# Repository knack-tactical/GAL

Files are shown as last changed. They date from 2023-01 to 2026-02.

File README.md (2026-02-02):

# An open-source 3D printed, Gun Aiming Laser!

<details><summary>How do I download the files from GitHub?</summary>

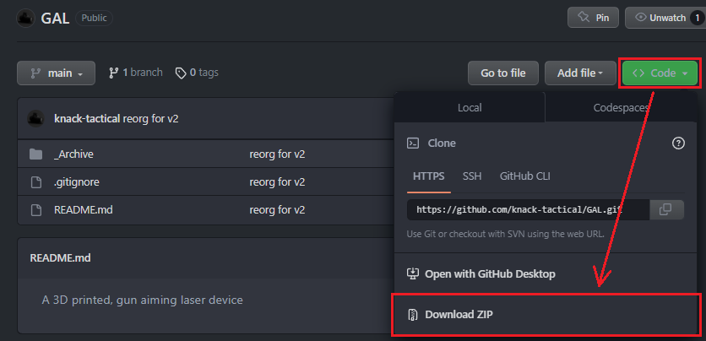
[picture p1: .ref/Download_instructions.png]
Click the green 'Code' button then 'Download ZIP'


</details>

## This project has sunset. Thank you all for your interest and support!

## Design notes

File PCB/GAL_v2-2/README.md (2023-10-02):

GAL v2.2 PCB changes from v2.1:
- Removed the area for the Pololu Buck Regulator
- Added an optional reverse polarity N-channel MOSFET (Q1)
   - This can be bypassed by shorting GND_IN to GND
   - If bypassing, conformal coating on the VCC pin is suggested

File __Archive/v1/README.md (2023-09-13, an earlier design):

# GAL
A 3D printed, gun aiming laser device

[Link to Falstad Circuit](https://tinyurl.com/2n3jw32g)

## Updated hardware from Swampdonkey's verison

Digi-key BOM: https://www.digikey.com/en/mylists/list/YLE6AURR2X

[M4x6x6mm Heatset Inserts](https://a.co/d/dzFERyy)

[850nm 3W LED](https://a.co/d/1zIGPuo)

[LED Lens](https://a.co/d/ejgL7wE)

## Things still in development
I am still working on a better retaining method for the laser zeroing, so any suggestions are appreciated!

I have designed a PCB for the GAL, which can be found [here](https://github.com/knack-69/GAL/blob/main/GAL_PCB.zip).

Also there are a few lasers I have tested with. The 980nm one is supposedly [30mW](https://www.aliexpress.us/item/2261799874302117.html). The other is a [5mW 850nm laser](https://www.aliexpress.us/item/2251832689759781.html) which is smaller and the one I will probably go with. For the 850nm laser, I bought the 'adjustable glass623' version, which performs well. Lots of testing on this front is needed. If you have any suggestions for lasers in this band, it would be appreciated as well.

## Suggested Print/Support Settings

I'd like to preface this by saying I'm not a 3D printing guru, my printers usually prints decently when I tell it to, so I don't mess around too much with the settings.
All .stl files are already in the suggested print orientation.

I would recommend not using a super large layer height (max I did was 0.18) as both male and female threads do better with smaller layer heights. Most of these pieces do not have very much interal wall volume, so using 3 walls and a lower infill (20%) should be plenty fine. Same goes with Top and Bottom layers. I usually go with 3 bottom layers and 3, which will make sure you don't see any of the infill through the top, which is especially important on the Lid, as the whole top surface is what you'll be looking at.

TL;DR: Layer Height: 0.18 | Walls: 3 | Bottom: 3 | Top: 3 | Infill 20%

### GAL Body

- Supports everywhere
- I had no issues with adhesion/warping

### GAL Lid

- Supports only on buildplate
  - This is because of the vertical laser adjustment nut hole is very small and getting supports out of it sounds terrible
- I had some issues with warping, but that might have just been me.
  - My issues with warping were because the long edge of the lid was directly at the edge of a piece of blue painters tape, which I use for bed adhesion.

### GAL Rail Mount. Battery Cover, Lens Lid

- No supports needed

### Selector Cap

- Supports everywhere

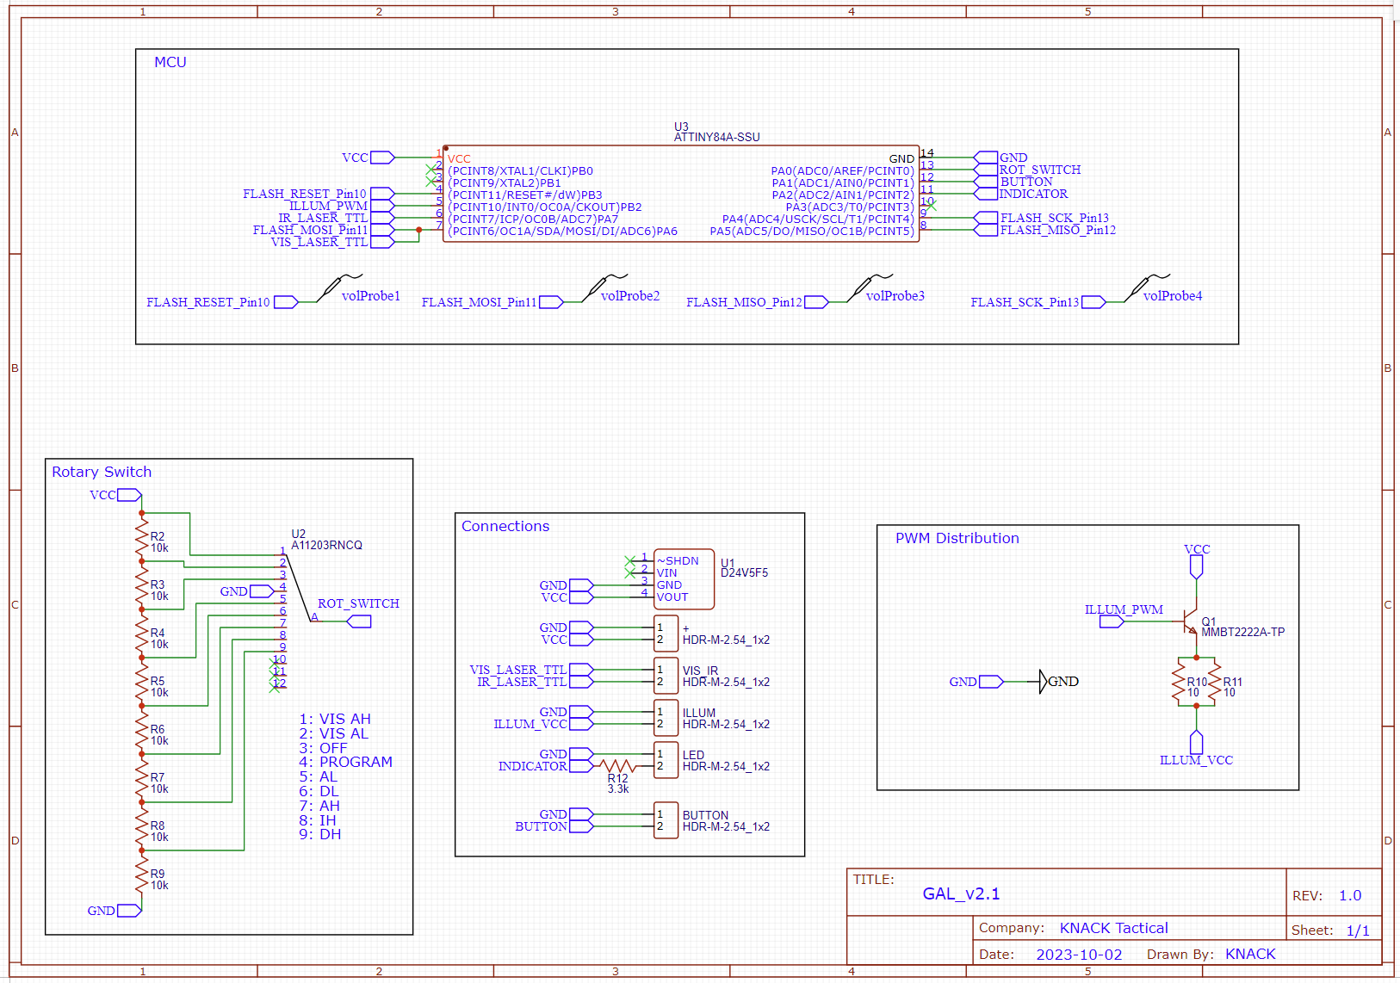
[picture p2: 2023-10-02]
PCB/GAL_v2-1/GAL_v2-1_schematic.png

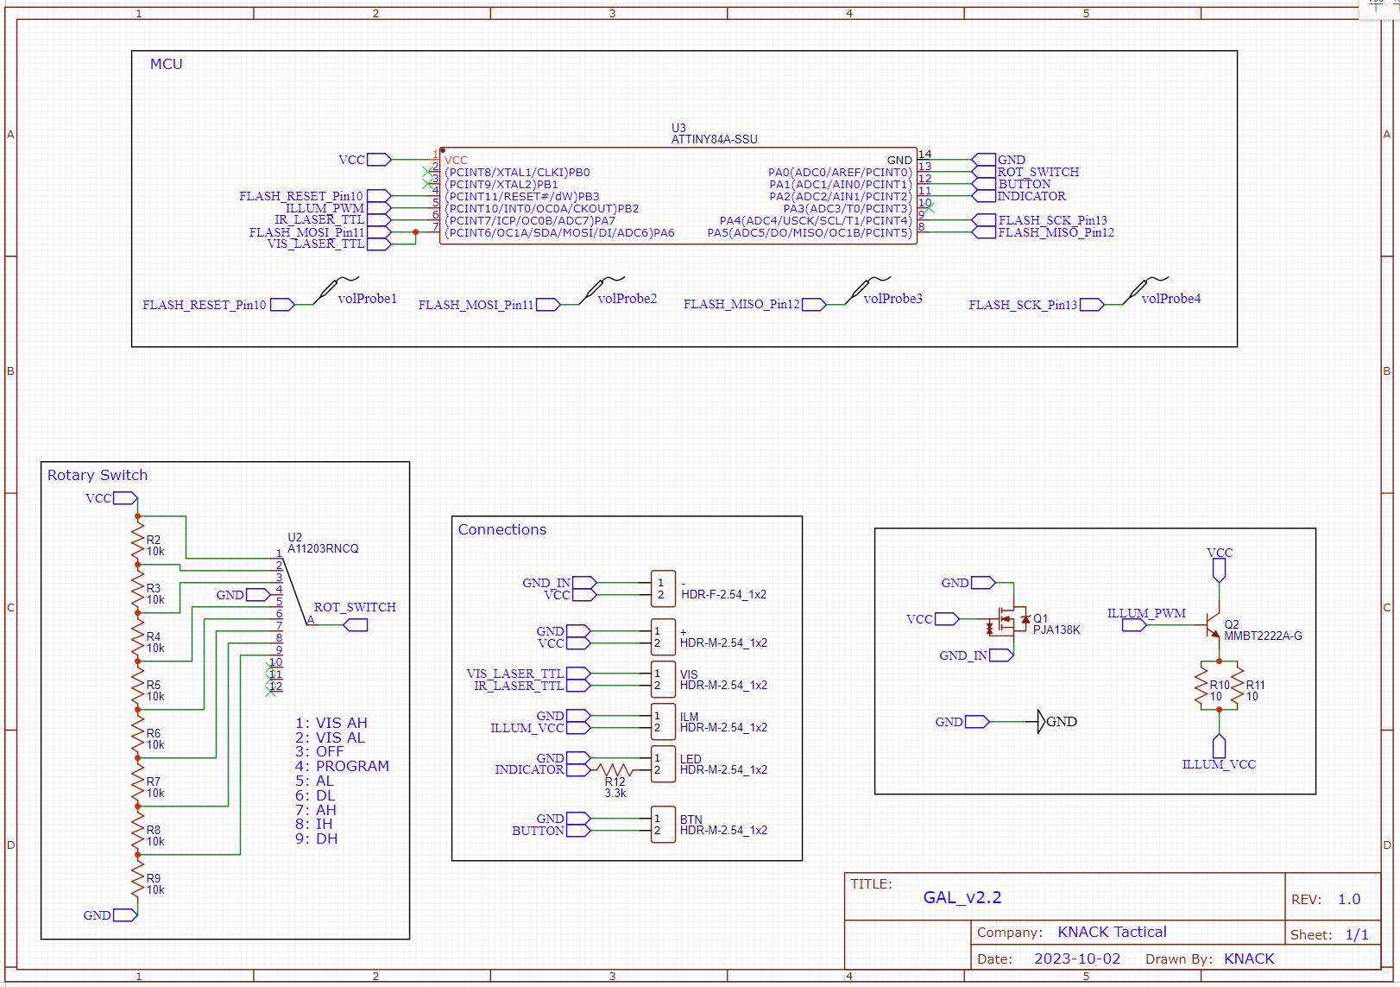
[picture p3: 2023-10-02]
PCB/GAL_v2-2/GAL_v2-2_schematic.png

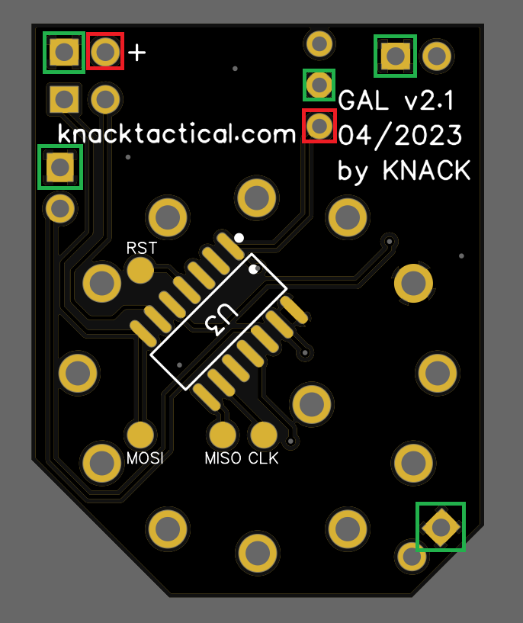
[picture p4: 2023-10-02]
attiny_program/VCC_GND_Pinout.png

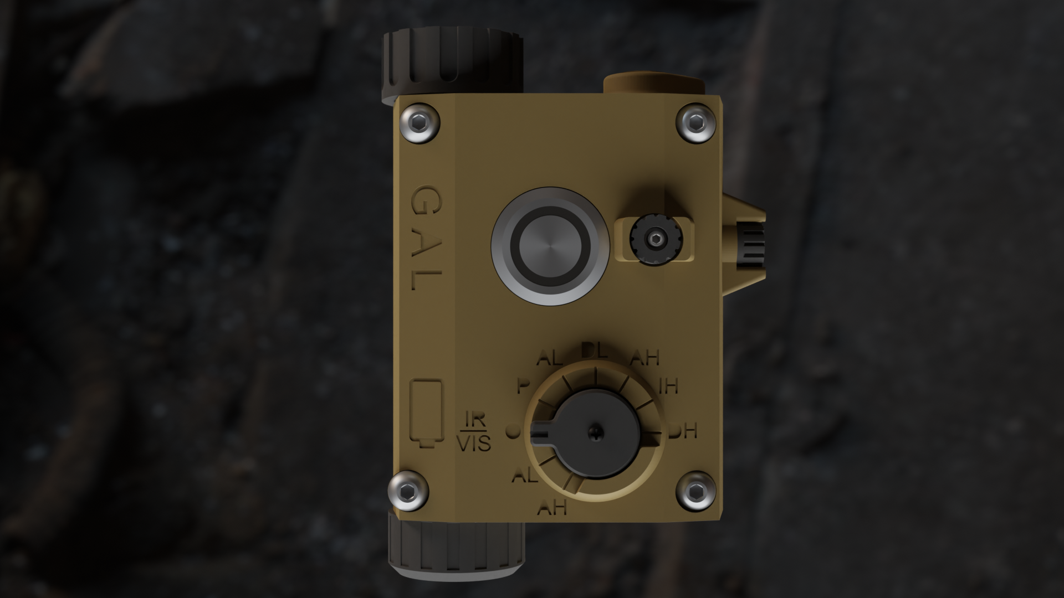
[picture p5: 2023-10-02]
Renders/top_angle_warehouse.png

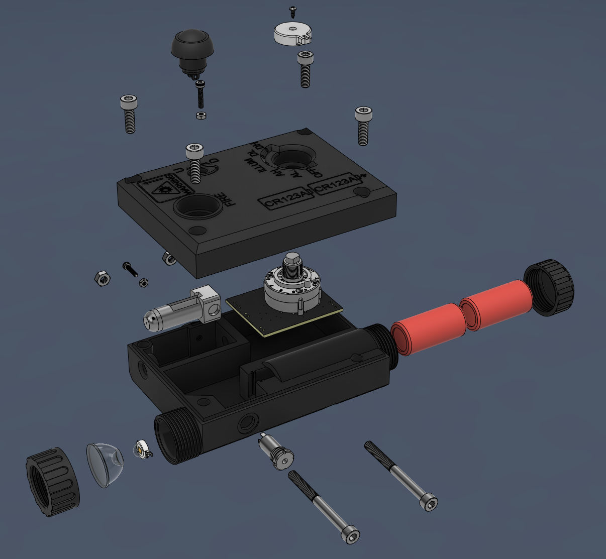
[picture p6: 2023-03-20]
RENDER/GAL_exploded_view.png

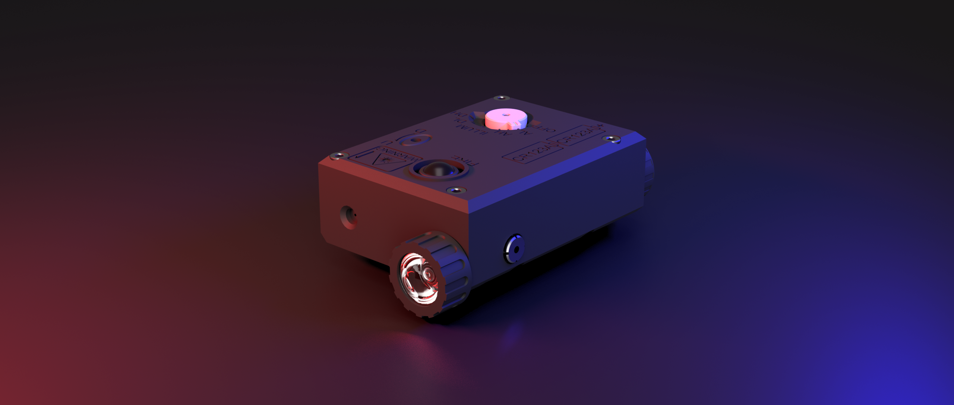
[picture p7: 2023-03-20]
RENDER/GAL_side.png

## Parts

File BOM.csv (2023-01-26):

Index | Manufacturer Part Number | Manufacturer Name | Description | Requested Quantity 1 | Pack Quantity 1 | Pack Type 1 | Digi-Key Part Number 1 | Unit Price 1 | Extended Price 1 | Minimum Order Quantity 1 | Customer Reference | Requested Part Number | Lead Weeks | Datasheet | Reference Designator | US Import Tariff | Original Part numbers | Image
1 | A20605RNCQ | C&K | SWITCH ROTARY 6POS 2.5A 125V | 1 | 1 | Tray | CKN9488-ND | 10.8 | $10.80 | 1 |  | CKN9488-ND | 16 | https://www.ckswitches.com/media/1349/arotary.pdf |  | - | CKN9488-ND | https://media.digikey.com/photos/CK%20Comp%20Photos/A20605RNCQ.jpg
2 | ASJ-203C-M-WP-HDW | Adam Tech | AUDIO JACK, WATERPROOF | 1 | 1 | Bulk | 2057-ASJ-203C-M-WP-HDW-ND | 3.91 | $3.91 | 1 |  | 2057-ASJ-203C-M-WP-HDW-ND | 10 | https://app.adam-tech.com/products/download/data_sheet/244313/asj-203c-m-wp-hdw-data-sheet.pdf |  | - | CP-2508-ND | https://media.digikey.com/Photos/Adam-Tech/ASJ-203C-M-WP-HDW.jpg
3 | PJA138K_R1_00001 | Panjit International Inc. | SOT-23, MOSFET | 1 | 1 | Cut Tape (CT) | 3757-PJA138K_R1_00001CT-ND | 0.24 | $0.24 | 1 |  | 3757-PJA138K_R1_00001CT-ND | 4 | https://www.panjit.com.tw/upload/datasheet/PJA138K.pdf |  | - | 3757-PJA138K_R1_00001CT-ND | https://media.digikey.com/Renders/~~Pkg.Case%20or%20Series/SOT-23-3%20PKG.jpg
4 | CL10B105KP8NNNC | Samsung Electro-Mechanics | CAP CER 1UF 10V X7R 0603 | 1 | 1 | Cut Tape (CT) | 1276-1946-1-ND | 0.1 | $0.10 | 1 |  | 1276-1946-1-ND | 22 | https://media.digikey.com/pdf/Data%20Sheets/Samsung%20PDFs/CL10B105KP8NNNC_Spec.pdf |  | - | 1276-1946-1-ND | https://media.digikey.com/Renders/Samsung%20Electro-Mechanics%20America/Ceramic-Capacitor-CL-Series.jpg
5 | 06035C102KAT2A | KYOCERA AVX | CAP CER 1000PF 50V X7R 0603 | 1 | 1 | Cut Tape (CT) | 478-1215-1-ND | 0.1 | $0.10 | 1 |  | 478-1215-1-ND | 12 | https://datasheets.kyocera-avx.com/X7RDielectric.pdf |  | May apply on shipments to the U.S. | 478-1215-1-ND | https://media.digikey.com/Renders/AVX%20Renders/0603-(1608-Metric)-0,90mm.jpg
6 | RNCP0805FTD1K00 | Stackpole Electronics Inc | RES 1K OHM 1% 1/4W 0805 | 3 | 3 | Cut Tape (CT) | RNCP0805FTD1K00CT-ND | 0.1 | $0.30 | 1 |  | RNCP0805FTD1K00CT-ND | 14 | https://www.seielect.com/Catalog/SEI-RNCP.pdf |  | - | RNCP0805FTD1K00CT-ND | https://media.digikey.com/Renders/Stackpole%20Renders/RNCP-Thin-Film-Chip-Resistor.jpg
7 | RC0805FR-07330RL | YAGEO | RES 330 OHM 1% 1/8W 0805 | 1 | 1 | Cut Tape (CT) | 311-330CRCT-ND | 0.1 | $0.10 | 1 |  | 311-330CRCT-ND | 20 | https://www.yageo.com/upload/media/product/productsearch/datasheet/rchip/PYu-RC_Group_51_RoHS_L_12.pdf |  | May apply on shipments to the U.S. | 311-330CRCT-ND | https://media.digikey.com/Renders/Yageo%20Renders/0805-(2012-Metric).jpg
8 | RC0805FR-073K3L | YAGEO | RES 3.3K OHM 1% 1/8W 0805 | 1 | 1 | Cut Tape (CT) | 311-3.30KCRCT-ND | 0.1 | $0.10 | 1 |  | 311-3.30KCRCT-ND | 20 | https://www.yageo.com/upload/media/product/productsearch/datasheet/rchip/PYu-RC_Group_51_RoHS_L_12.pdf |  | - | 311-3.30KCRCT-ND | https://media.digikey.com/Renders/Yageo%20Renders/0805-(2012-Metric).jpg
9 | 1N4448W-TP | Micro Commercial Co | DIODE GEN PURP 75V 250MA SOD123 | 6 | 6 | Cut Tape (CT) | 1N4448WTPMSCT-ND | 0.11 | $0.66 | 1 |  | 1N4448WTPMSCT-ND | 10 | https://www.mccsemi.com/pdf/Products/1N4448W(SOD-123).pdf |  | May apply on shipments to the U.S. | 1N4448WTPMSCT-ND | https://media.digikey.com/Renders/Micro%20Commercial%20Renders/SOD-123.jpg
10 | TLC555CDR | Texas Instruments | IC OSC SGL TIMER 2.1MHZ 8-SOIC | 1 | 1 | Cut Tape (CT) | 296-1336-1-ND | 0.85 | $0.85 | 1 |  | 296-1336-1-ND | 6 | https://www.ti.com/general/docs/suppproductinfo.tsp?distId=10 |  | - | 296-1336-1-ND | https://media.digikey.com/Renders/Texas%20Instr%20Renders/8-SOIC.jpg

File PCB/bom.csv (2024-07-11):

Designator | Footprint | Quantity | Value | LCSC Part #
C1, C2 | 0402 | 2 | 1u
J1, J2 | JST_SH_SM06B-SRSS-TB_1x06-1MP_P1.00mm_Horizontal | 2 | SM06B-SRSS-TB
J3 | PinHeader_2x03_P2.00mm_Vertical | 1 | Conn_02x03
Q1 | SOT-723 | 1 | WPM2031-3/TR
R1 | 0402 | 1 | 4.7k
R2 | 0402 | 1 | 2.55
R4 | 0402 | 1 | 1M
R5 | 0402 | 1 | 220k
SW1 | SW_Push_1P1T-SH_NO_CK_KMR2xxG | 1 | KMR221GLFS
U1 | SOIC-14_3.9x8.7mm_P1.27mm | 1 | ATtiny84A-SS
U2 | 220AMB10R-SMD | 1 | 220AMB10R
U3 | DRV0006A_NV | 1 | TPS74501PDRVR
U4 | SC-74-6_1.5x2.9mm_P0.95mm | 1 | BCR421UW6

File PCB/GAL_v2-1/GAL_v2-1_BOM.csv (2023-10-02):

ID | Name | Designator | Footprint | Quantity | Manufacturer Part | Manufacturer | Supplier | Supplier Part | Price
1 | HDR-M-2.54_1x2 | +,BUTTON,ILLUM,LED,VIS_IR | HDR-M-2.54_1X2 | 5 |  |  | LCSC | C124375 | 0.022
2 | MMBT2222A-TP | Q1 | SOT-23-3_L2.9-W1.3-P1.90-LS2.4-BR | 1
3 | 10k | R2,R3,R4,R5,R6,R7,R8,R9 | R0805 | 8 | RC0805JR-0710KL | YAGEO(国巨) | LCSC | C100047 | 0.002
4 | 10 | R10,R11 | R0805 | 2 | TC0525F100JT5E | UNI-ROYAL(厚声) | LCSC | C109436 | 0.009
5 | 3.3k | R12 | R0805 | 1 | RC0805FR-073K3L | YAGEO(国巨) | LCSC | C114531 | 0.002
6 | D24V5F5 | U1 | POLOLU_D24V5F5 | 1 | D24V5F5 | Pololu | Pololu | D24V5F5
7 | A11203RNCQ | U2 | SW-TH_CK_A112XXXXCXX | 1 | A11203RNCQ | C&K | LCSC | C411884 | 7.25
8 | ATTINY84A-SSU | U3 | SOIC-14_L8.7-W3.9-P1.27-LS6.0-BL | 1 | ATTINY84A-SSU | MICROCHIP(美国微芯) | LCSC | C144333 | 4.259

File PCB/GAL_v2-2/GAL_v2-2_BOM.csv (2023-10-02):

ID | Name | Designator | Footprint | Quantity | Manufacturer Part | Manufacturer | Supplier | Supplier Part | Price
1 | HDR-F-2.54_1x2 | GND | HDR-F-2.54_1X2 | 1 |  |  | LCSC | C49661 | 0.035
2 | ATTINY84A-SSU | U3 | SOIC-14_L8.7-W3.9-P1.27-LS6.0-BL | 1 | ATTINY84A-SSU | MICROCHIP(美国微芯) | LCSC | C144333 | 4.259
3 | 10 | R10,R11 | R0805 | 2 | TC0525F100JT5E | UNI-ROYAL(厚声) | LCSC | C109436 | 0.009
4 | MMBT2222A-G | Q2 | SOT-23-3_L2.9-W1.6-P1.90-LS2.8-BR | 1
5 | HDR-M-2.54_1x2 | VIS,BTN,LED,+,ILM | HDR-M-2.54_1X2 | 5 |  |  | LCSC | C124375 | 0.022
6 | 3.3k | R12 | R0805 | 1 | RC0805FR-073K3L | YAGEO(国巨) | LCSC | C114531 | 0.002
7 | PJA138K | Q1 | SOT-23_L2.9-W1.3-P1.90-LS2.4-BR | 1 | PJA138K_R1_00001 | PANJIT(强茂) | LCSC | C2902548 | 0.036
8 | 10k | R2,R3,R4,R5,R6,R7,R8,R9 | R0805 | 8 | RC0805JR-0710KL | YAGEO(国巨) | LCSC | C100047 | 0.002
9 | A11203RNCQ | U2 | SW-TH_CK_A112XXXXCXX | 1 | A11203RNCQ | C&K | LCSC | C411884 | 7.25

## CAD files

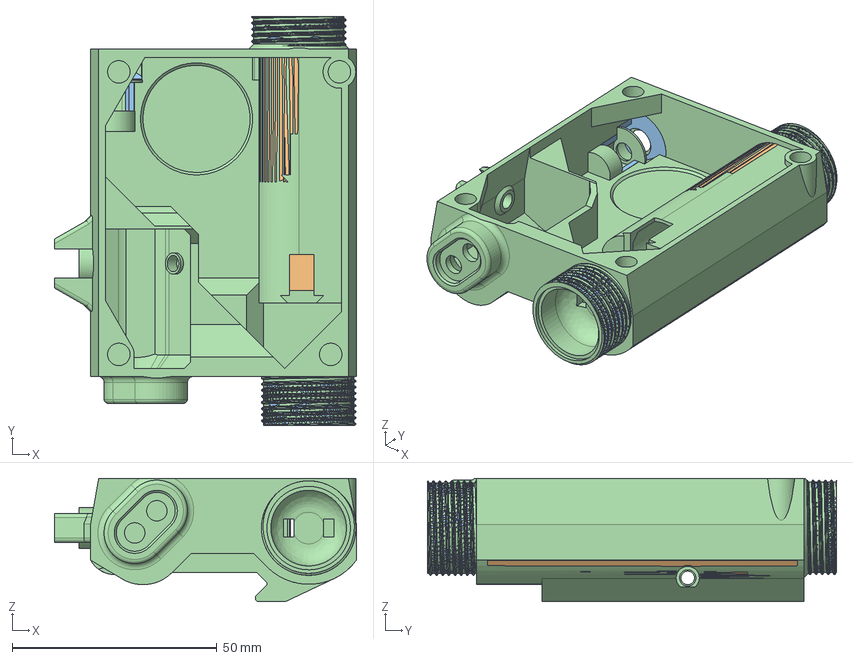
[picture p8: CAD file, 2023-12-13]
STEP/Body_Variants.step
73.8 x 100.0 x 30.2 mm
body_cr123_jack
body_cr123_crane
body_18650_jack
body_18650_crane

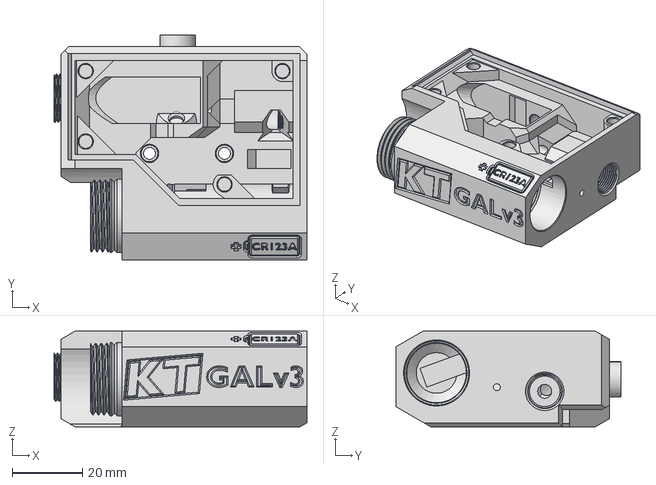
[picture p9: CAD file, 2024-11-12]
STEP/community_mods/SureFire_Pattern_Illumintor_GAL_Body.step
72.2 x 64.4 x 27.3 mm

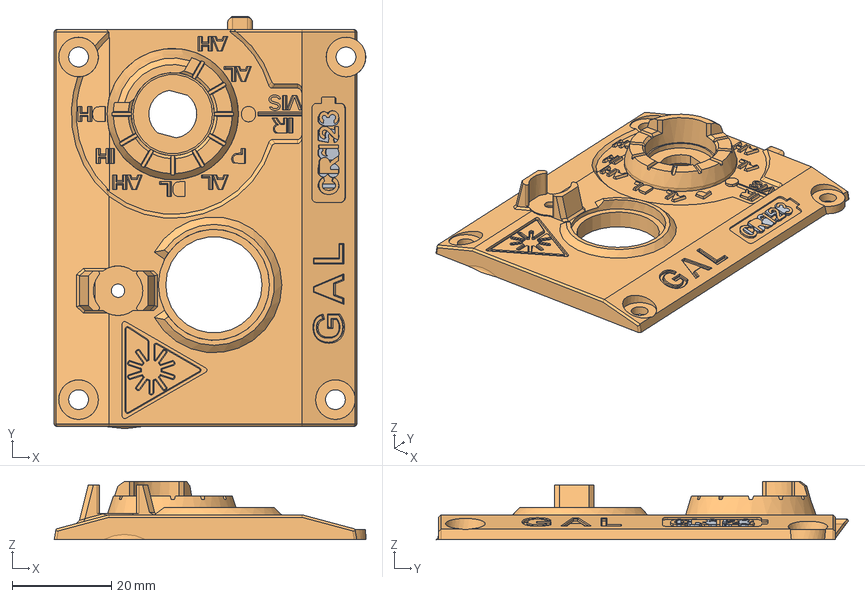
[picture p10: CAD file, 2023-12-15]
STEP/edits_by_zb/GAL_lid_variants_zb.step
62.8 x 83.1 x 11.8 mm
lid_18650_zb
lid_cr123_zb

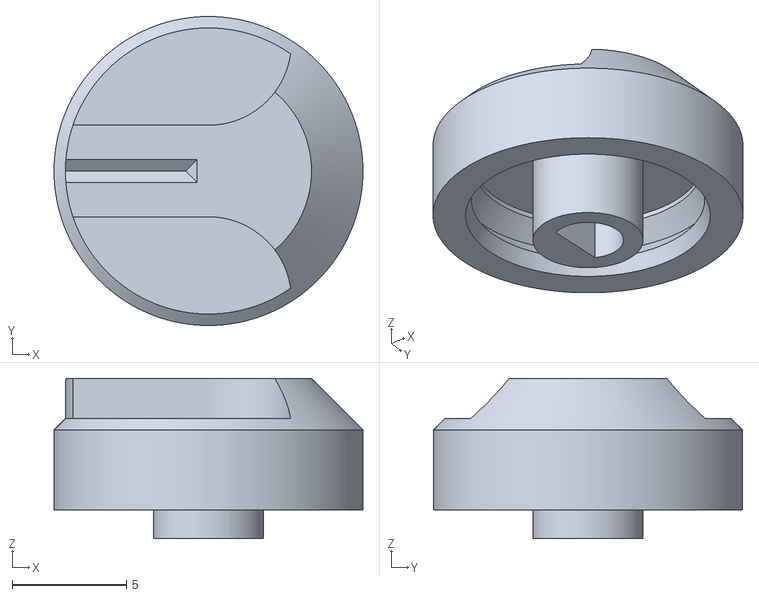
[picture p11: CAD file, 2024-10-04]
STL/11_selector_knob_2.stl
13.5 x 13.5 x 7.00

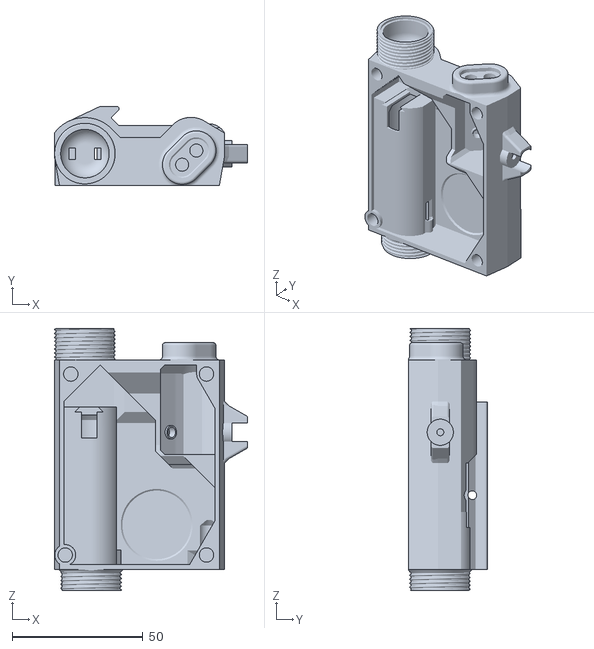
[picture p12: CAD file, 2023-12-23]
STL/body_variants/body_18650_jack.stl
73.8 x 30.2 x 100.0

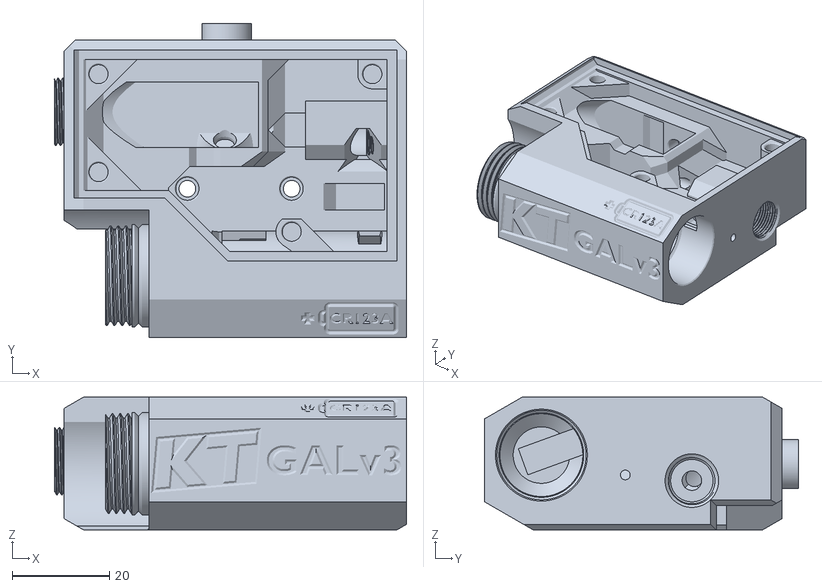
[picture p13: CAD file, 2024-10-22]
STL/community_mods/mod_02_SureFire_Pattern_Illumintor_GAL_Body.stl
72.2 x 64.4 x 27.3

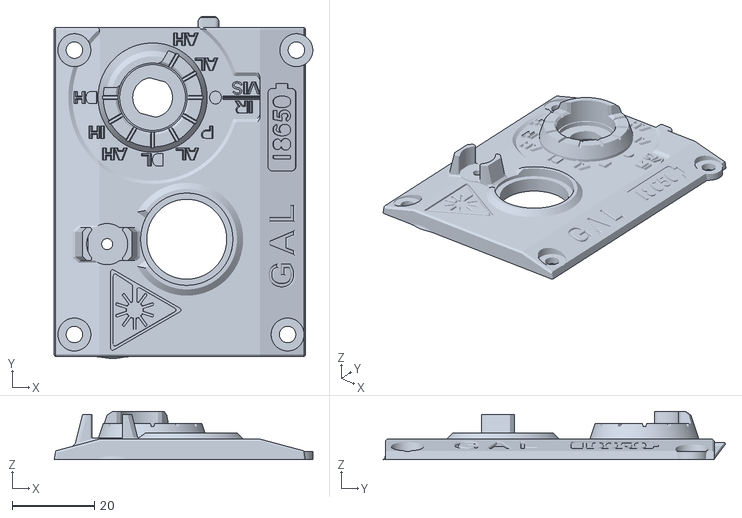
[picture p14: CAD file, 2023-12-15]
STL/edits_by_zb/GAL_lid_18650_zb.stl
62.8 x 83.1 x 11.8

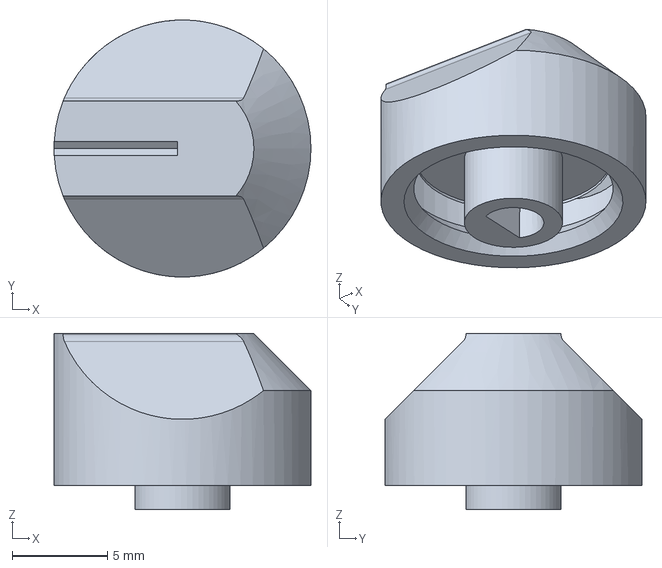
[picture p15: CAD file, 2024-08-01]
STEP/community_mods/selector_knob_zb.step
13.5 x 13.5 x 9.25 mm

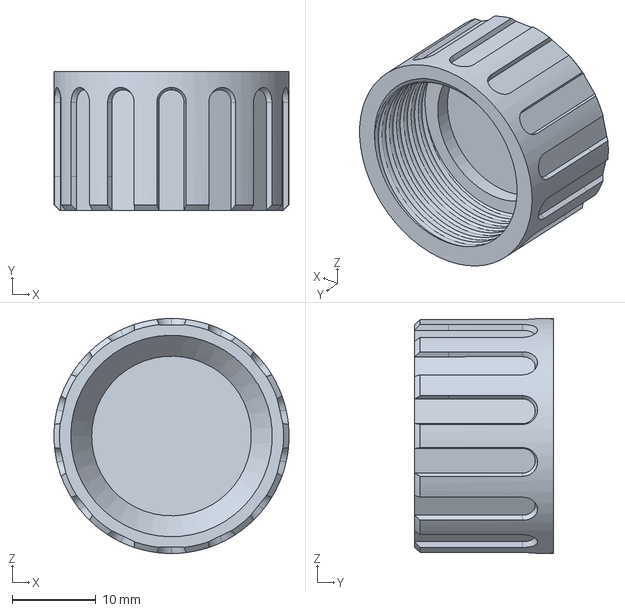
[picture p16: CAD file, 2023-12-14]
STEP/edits_by_zb/GAL_lens_cap-bezel_zb.step
28.0 x 16.5 x 28.0 mm

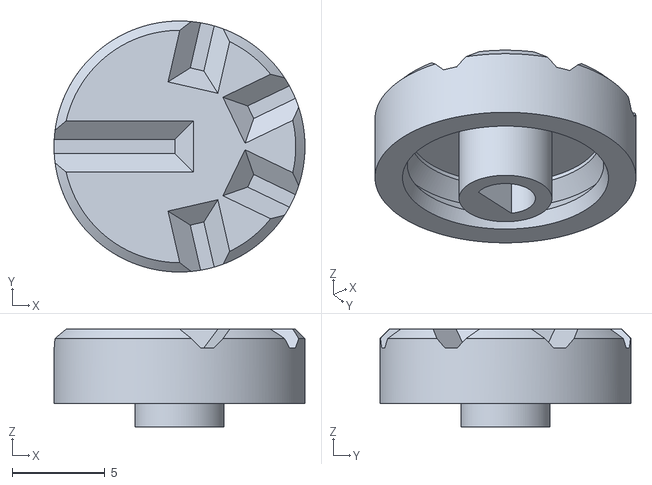
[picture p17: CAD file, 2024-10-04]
STL/11_selector_knob.stl
13.5 x 13.5 x 5.25

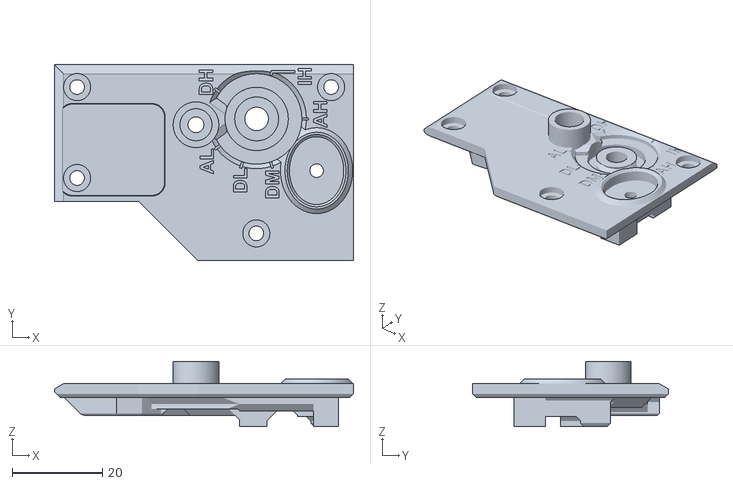
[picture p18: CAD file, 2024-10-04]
STL/community_mods/mod_03_GAL_Lid.stl
66.1 x 43.3 x 14.4

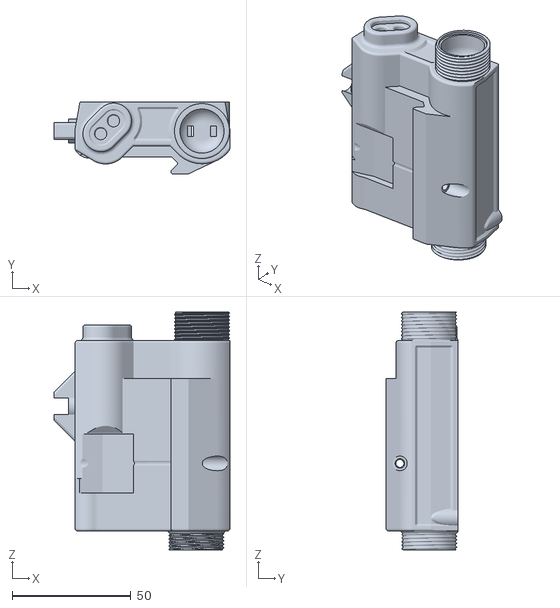
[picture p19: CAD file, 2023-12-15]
STL/edits_by_zb/GAL_body_CR123_crane_zb.stl
73.8 x 30.2 x 100.0

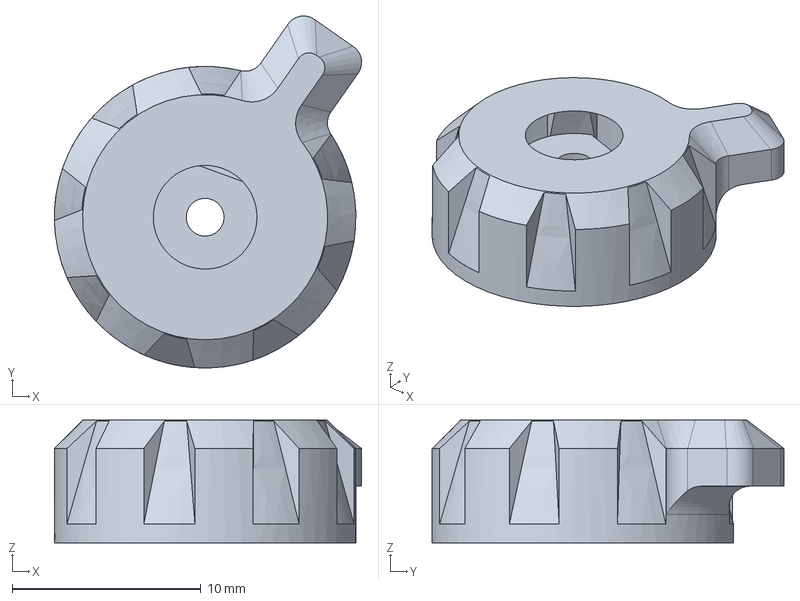
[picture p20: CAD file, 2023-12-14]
STEP/edits_by_zb/GAL_selector_knob_zb.step
16.3 x 18.7 x 6.50 mm

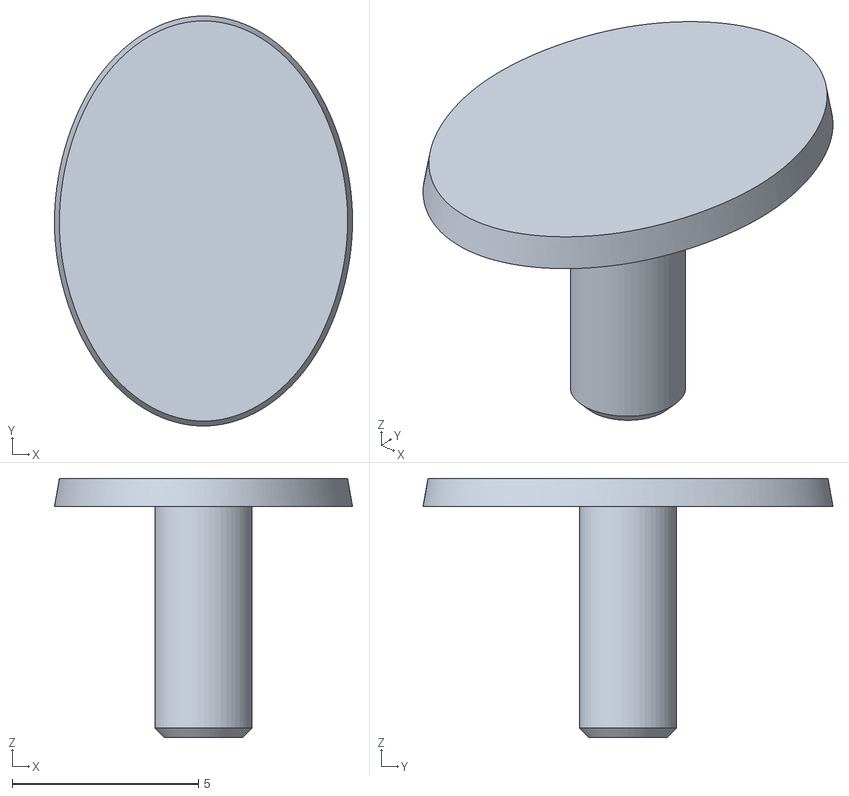
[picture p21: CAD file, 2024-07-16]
STL/12_button_post.stl
8.00 x 11.0 x 6.95

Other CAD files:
STL/community_mods/mod_03_selector_knob.stl
STL/edits_by_zb/GAL_lid_CR123_zb.stl
STEP/edits_by_zb/GAL_battery_cap_retention_zb.step
STL/07_crane_port_spacer.stl
STEP/edits_by_zb/GAL_TPU_gaskets_retention_zb.step
STL/01_GAL_body.stl
STL/02_laser_base.stl
STL/03_laser_housing.stl
STL/04_laser_lens_cap.stl
STL/05_lens_cap.stl
STL/06_lens_locking_ring.stl
STL/08_crane_port_installation_tool.stl
STL/09_battery_cap_retention_strap_TPU.stl
STL/10_GAL_lid.stl
STL/13_button_retainer.stl
STL/14_FIRE_button_TPU.stl
STL/Battery Cover.stl
STL/GAL Rail Mount.stl
STL/Laser Base.stl
STL/Laser Body.stl
STL/Selector Cap.stl
STL/adjustment_locking_knob.stl
STL/battery_cap.stl
STL/community_mods/mod_01_selector_knob_zb.stl
STL/community_mods/mod_03_GAL_Lid_reordered.stl
STL/edits_by_zb/GAL_TPU_gaskets_retention_zb.stl
STL/edits_by_zb/GAL_battery_cap_retention_zb.stl
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

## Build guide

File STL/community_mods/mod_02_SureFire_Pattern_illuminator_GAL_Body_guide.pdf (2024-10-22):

This is the GALv3 Body mod that accepts SureFire patterned flashlight heads.

This includes M300 heads, Kiji heads, Malkoff E2XT, etc.

The same o-ring used for the GALv3 adjustable illuminator can be used (15x1.5mm o-ring)

Build Instructions:

- The Illum- wire should be stripped and tinned about 0.5" long.
- Feed the wire into the hole on the inside of the threaded area until the insulation is all the way to the hole.
- This is to prevent shorting between the positive and negative terminals
- Feed the tinned wire up along the channel, and hook it over the top and back into the inside.
- Trim off any excess that goes too far into the inside area.
- The Illum+ wire should be soldered to a AAA positive terminal (no spring) and glued into the bottom of the inside area
- Some other contact can be used, just make sure it doesn’t contact the negative wire

Note: In the images, the wire colors are backwards. Take note of which wire you are wires you are wiring to which part.

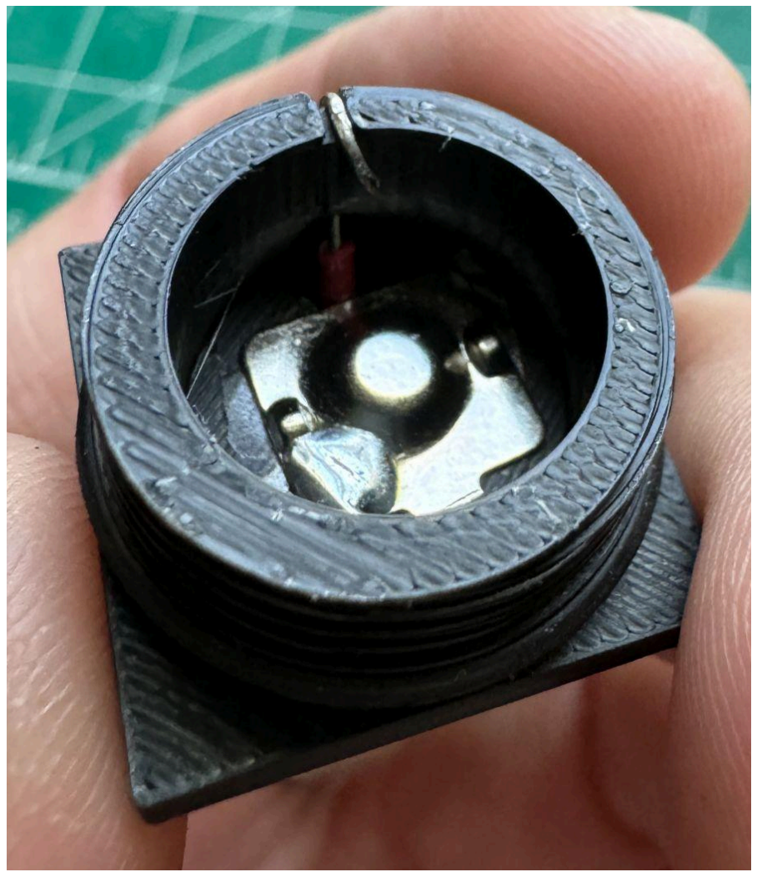
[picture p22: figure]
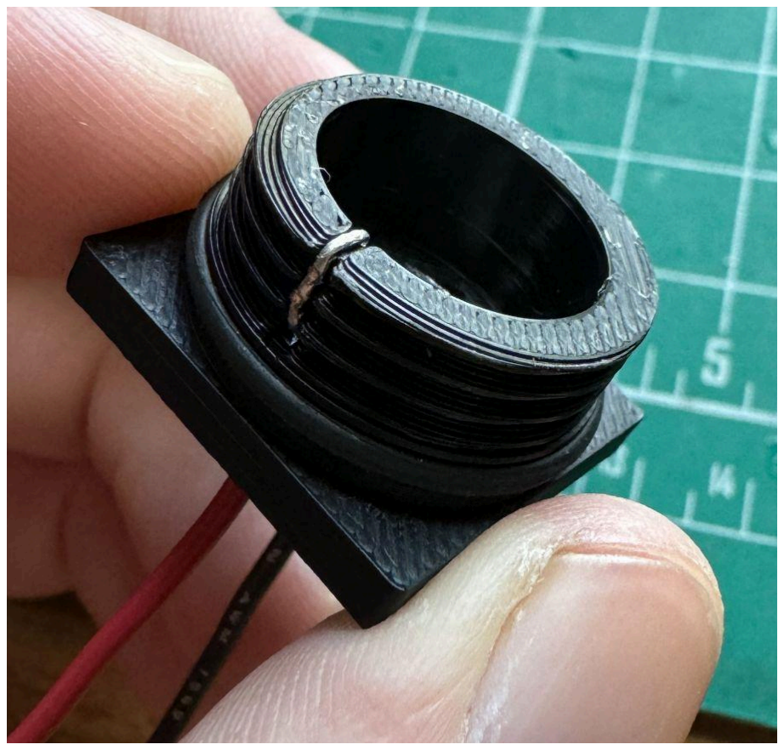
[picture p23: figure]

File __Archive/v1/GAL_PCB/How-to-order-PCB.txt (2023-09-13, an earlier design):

How to Order PCB

Please refer to:
https://docs.easyeda.com/en/PCB/Order-PCB

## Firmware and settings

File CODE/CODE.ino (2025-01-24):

/*  The code for the GALv3
 *  by KNACK
 */
#include <avr/interrupt.h>
#include <avr/sleep.h>
#include <avr/power.h>
#define time_t unsigned long
#define round(N) ((N) >=0)? (int)((N)+0.5) : (int)((N)-0.5)

/*                    ATtiny84  Pinout
 *                         ______
 *                 VCC - 1|o     |14- GND
 *           (10)  PB0 - 2|      |13- PA0  (0/A0)
 *            (9)  PB1 - 3|      |12- PA1  (1/A1)
 *     RESET (11)  PB3 - 4|      |11- PA2  (2/A2)
 *            (8) PB2* - 5|      |10- PA3  (3/A3)
 *         (7/A7) PA7* - 6|      |9 - PA4  (4/A4) SCK
 *    MOSI (6/A6) PA6* - 7|______|8 - PA5* (5/A5) MISO
 *        
 */

/*                   ATtiny84 Pin Map
 *  IC PIN  | ATtiny PIN  | ARDUINO PIN | SPECS           | FUNCTION
 *  1         VCC           VCC           VCC               VCC
 *  2         PB0           10            XTAL1             N/C
 *  3         PB1           9             XTAL2             N/C
 *  4         PB3           11            RESET             FLASH_RESET_PIN_10
 *  5         PB2           8             INT0, PWM         INDICATOR
 *  6         PA7           7/A7          ADC, PWM          ILLUM_PWM
 *  7         PA6           6/A6          ADC, PWM, MOSI    FLASH_MOSI_PIN11, VIS_LASER_TTL
 *  8         PA5           5/A5          ADC, PWM, MISO    FLASH_MISO_PIN12, IR_LASER_TTL
 *  9         PA4           4/A4          ADC, SCK          FLASH_SCK_PIN13, BUTTON
 *  10        PA3           3/A3          ADC               SW_2
 *  11        PA2           2/A2          ADC, AIN1         SW_8
 *  12        PA1           1/A1          ADC, AIN0         SW_1
 *  13        PA0           0/A0          ADC, AREF         SW_4
 *  14        GND           GND           GND               GND
 */


/*  Functions needed:
 *  SW_1:                 digitalRead()
 *  SW_2:                 digitalRead()
 *  SW_4:                 digitalRead()
 *  SW_8:                 digitalRead()
 *  BUTTON:               interrupt (PA0-7)   PA4
 *  FLASH_SCK_PIN13:      SCK                 PA4
 *  FLASH_MISO_PIN12:     MISO                PA6
 *  FLASH_MOSI_PIN11:     MOSI                PA5
 *  FLASH_RESET_PIN_10:   RESET pin           PB3
 *  VIS_LASER_TTL:        PWM (PA5-7, PB2)    PA6
 *  IR_LASER_TTL:         PWM (PA5-7, PB2)    PA5
 *  INDICATOR:            digitalWrite()      PB2
 *  ILLUM_PWM:            PWM (PA5-7, PB2)    PA7
 */

// Pin Variables 
#define SW_1            1
#define SW_2            3
#define SW_4            0
#define SW_8            2
// #define VIS_PIN         6
#define IR_PIN          5
#define ILLUM_PIN       7
#define BUTTON_PIN      4
#define INDICATOR_PIN   8

// Program Constants
#define SHUTOFF_TIMEOUT       30500 // ms until button press timeout counter increments | ~30s
#define TIMEOUT_COUNT_LIMIT   10    // number of timeout counter increments until shutdown | 10 x 30s = 5min
#define BLINK_SPEED_SLOW      60    // ms between blink state changes
#define SLEEP_TIMEOUT         500   // ms delay until allowed to sleep
#define LOW_BATTERY_MV        2625  // Maximum level for a low battery warning in mV (accounting for voltage drop)
#define DBL_PRESS_MAX         300   // max ms between clicks to enable double-press-to-hold
#define DBL_PRESS_MIN         25    // min ms between clicks to enable double-press-to-hold (debounce)

#define ILLUM_HIGH  100   // % of power for the illuminator high mode
#define ILLUM_MED   50    // % of power for the illuminator medium mode
#define ILLUM_LOW   20    // % of power for the illuminator low mode
#define LASER_HIGH  100   // % of power for the laser high mode (5mW)
#define LASER_MED   50    // % of power for the laser medium mode (2.5mW)
#define LASER_LOW   5     // % of power for the laser low mode (0.25mW)

// Brightness Settings
const short il_h = round(ILLUM_HIGH / 100.0 * 255);
const short il_m = round(ILLUM_MED  / 100.0 * 255);
const short il_l = round(ILLUM_LOW  / 100.0 * 255);
const short la_h = round(LASER_HIGH / 100.0 * 255);
const short la_m = round(LASER_MED  / 100.0 * 255);
const short la_l = round(LASER_LOW  / 100.0 * 255);

//            Positions:    0,    1,     2,     3,     4,     5,     6,     7,     8,     9
//            Modes:        OFF,  DH,    OFF,   IH,    OFF,   AH,    OFF,   DM,    DL,    AL
const short ir_val[10] =    {0,    la_h,  0,     0,     0,     la_h,  0,     la_m,  la_l,  la_l};
const short illum_val[10] = {0,    il_h,  0,     il_h,  0,     0,     0,     il_m,  il_l,  0};

// Misc Variables
int timeout_count = 0;            // counter for 5-min timeout
time_t current_time = 0;

bool button_pressed = false;
bool dbl_pressed = false;
time_t dbl_down_time = 0;

float batt_v;
time_t fade_time = 0;
int fade_value = 255;
bool fade_up = false;

///////////////////////////////
///        Interrupt        ///
///////////////////////////////

ISR(PCINT0_vect) {
  ADCSRA &= bit(ADEN);
  power_all_enable();
  current_time = millis();
  noInterrupts();
  if (!digitalRead(BUTTON_PIN)) {
    if (!button_pressed) {
      dbl_pressed = (current_time > DBL_PRESS_MAX && 
                      current_time - dbl_down_time < DBL_PRESS_MAX && 
                      current_time - dbl_down_time > DBL_PRESS_MIN);
      dbl_down_time = current_time;

      button_pressed = true;
      digitalWrite(INDICATOR_PIN, HIGH);
      set_outputs();
    }
  } else {
    button_pressed = false;
    if (!dbl_pressed) {
      analogWrite(IR_PIN, 0);
      analogWrite(ILLUM_PIN, 0);
      digitalWrite(INDICATOR_PIN, LOW);
    }
  }
  timeout_count = 0;
  interrupts();
}

//////////////////////////////
///      Setup & Loop      ///
//////////////////////////////

void setup() {
  pinMode(BUTTON_PIN, INPUT_PULLUP);
  pinMode(SW_1, INPUT);
  pinMode(SW_2, INPUT);
  pinMode(SW_4, INPUT);
  pinMode(SW_8, INPUT);
  pinMode(INDICATOR_PIN, OUTPUT);
  GIMSK = 0b00010000;
  PCMSK0 = 0b00010000;
  set_sleep_mode(SLEEP_MODE_PWR_DOWN);

  // Force set_outputs() if button pressed when device started
  if (!digitalRead(BUTTON_PIN)) {
    button_pressed = true;
    digitalWrite(INDICATOR_PIN, HIGH);
    set_outputs();
  }
  batt_v = read_vcc();
}

void loop() {
  // if active, count time active
  if (button_pressed || dbl_pressed) {
    if (millis() - current_time >= SHUTOFF_TIMEOUT) {    
      current_time = millis();
      timeout_count++;
    }

    // If low battery, slow blink indicator when activated
    if (batt_v <= LOW_BATTERY_MV) {
      if (millis() - fade_time >= BLINK_SPEED_SLOW) {
        if (fade_up) {
          fade_value += 5;
          fade_up = !(fade_value >= 255);
        } else {
          fade_value -= 5;
          fade_up = fade_value <= 0;
        }
        analogWrite(INDICATOR_PIN, fade_value);
        fade_time = millis();
      }
    }
  }

  // If not activated or TIMEOUT_COUNT_LIMIT reached, shut off
  if ((!button_pressed && !dbl_pressed) || timeout_count >= TIMEOUT_COUNT_LIMIT ) {
    dbl_pressed = false;
    if (millis() - current_time >= SLEEP_TIMEOUT) {
      analogWrite(IR_PIN, 0);
      analogWrite(ILLUM_PIN, 0);
      digitalWrite(INDICATOR_PIN, LOW);
      delay(1000);
      batt_v = read_vcc();
      ADCSRA &= ~ bit(ADEN);
      power_all_disable();
      sleep_mode();
    }
  }
}

///////////////////////////////
///        Functions        ///
///////////////////////////////

void set_outputs() {
  pinMode(SW_1, INPUT_PULLUP);
  pinMode(SW_2, INPUT_PULLUP);
  pinMode(SW_4, INPUT_PULLUP);
  pinMode(SW_8, INPUT_PULLUP);
  bool sw_1 = digitalRead(SW_1);
  bool sw_2 = digitalRead(SW_2);
  bool sw_4 = digitalRead(SW_4);
  bool sw_8 = digitalRead(SW_8);
  pinMode(SW_1, INPUT);
  pinMode(SW_2, INPUT);
  pinMode(SW_4, INPUT);
  pinMode(SW_8, INPUT);

  int pos = (0 << 3) | !sw_8 << 3 | !sw_4 << 2 | !sw_2 << 1 | !sw_1;
  analogWrite(IR_PIN, ir_val[pos]);
  analogWrite(ILLUM_PIN, illum_val[pos]);
}

long read_vcc() {
  long result;
  // Read 1.1V reference against AVcc
  ADMUX = 0b00100001;// adc source=1.1 ref; adc ref (base for the 1023 maximum)=Vcc
  delay(2); // Wait for Vref to settle
  ADCSRA |= 1<<ADSC; // Convert
  while (bit_is_set(ADCSRA,ADSC));
  result = ADCL;
  result |= ADCH<<8;
  result = 1126400L / result; // Back-calculate AVcc in mV
  return result;
}

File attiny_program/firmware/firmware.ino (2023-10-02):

#include <avr/interrupt.h>
#include <avr/sleep.h>
#define time_t unsigned long

// Pin Variables
int rotarySwitch = A0;
int vis = 6;
int ir = 7;
int illum = 8;
int buttonPin = 1;
int indicator = 2;

// PWM Variables
int numSteps = 8;
float threshold = 1024.0 / numSteps;

// Programming
bool programming = false;
int blinkSpeed = 100; // ms between blink state changes
bool buttonPressed = false;

// Brightness Settings
int brightPct = 100;
int dimPct = 20;
float b = brightPct / 100.0 * 255;
float d = dimPct / 100.0 * 255;
//                // VH,     VL,  O, AL,  DL,  AH,     IH,     DH,     P
//int visVal[9] =   {bright, dim, 0, 0,   0,   0,      0,      0,      0};
//int irVal[9] =    {0,      0,   0, dim, dim, bright, 0,      bright, 0};
//int illumVal[9] = {0,      0,   0, 0,   dim, 0,      bright, bright, 0};
//int ppsVal[9] =   {0,      0,   0, 0,   1,   2,      4,      8,      0};

                // P  DH  IH  AH  DL  AL  O  VL  VH
int visVal[9] =   {0, 0,  0,  0,  0,  0,  0, d,  b};
int irVal[9] =    {0, b,  0,  b,  d,  d,  0, 0,  0};
int illumVal[9] = {0, b,  b,  0,  d,  0,  0, 0,  0};
int ppsVal[9] =   {0, 8,  4,  2,  1,  0,  0, 0,  0};
int programPos = 0;

// Illum Settings
int pulsePerSec = 0;
int flashRate, flashRateBase = 1000;
float illumBrightness;
time_t timeout = 30500; // sec until button press times out
int timeout_count_limit = 10, timeout_count = 0;
time_t current_t = 0;
bool doIllumLoop = false;
time_t currentMillis, previousMillis = 0;
int illumState = illumBrightness;

// Double click variables
int dblPressInterval = 250; // max ms between clicks to enable double-press-to-hold
time_t dblDownTime = 0;
bool dblPressed = false;
time_t sleepTimeout = 300; // ms until sleep

///////////////////////////////
///        Interrupt        ///
///////////////////////////////

ISR(PCINT0_vect) {
  current_t = millis();
  noInterrupts();
  timeout_count = 0;
  if (!digitalRead(buttonPin)) { // Button Pressed
    if (!buttonPressed) { // This prevents multiple interrupts
      if (current_t - dblDownTime < dblPressInterval && current_t > dblPressInterval) { 
        dblPressed = true;
      } else {
        dblPressed = false;
      }
      dblDownTime = current_t;
      buttonPressed = true;
      digitalWrite(indicator, HIGH);
      setOutputs();
    }
  } else {
    if (programming) {
      getPulsePerSec();
      programming = false;
    }
    buttonPressed = false;
    if (!dblPressed) {
      doIllumLoop = false;
      analogWrite(vis, 0);
      analogWrite(ir, 0);
      analogWrite(illum, 0);
      digitalWrite(indicator, LOW);
    }
  }
  interrupts();
}

//////////////////////////////
///      Setup & Loop      ///
//////////////////////////////

void setup() {
  pinMode(buttonPin, INPUT_PULLUP);
  pinMode(indicator, OUTPUT);
  GIMSK = 0b00010000;
  PCMSK0 = 0b00000010;
  set_sleep_mode(SLEEP_MODE_PWR_DOWN);
}

void loop() {
  if ((buttonPressed || dblPressed) && doIllumLoop ) {
    currentMillis = millis();
    if (currentMillis - previousMillis >= flashRate) {
      previousMillis = currentMillis;
      illumState = (illumState == 0) ? illumBrightness : 0;
      analogWrite(illum, illumState);
    }
  }
  if (millis() - current_t >= timeout) {
    current_t = millis();
    timeout_count++;
  }
  if ((!buttonPressed && !dblPressed) || timeout_count >= timeout_count_limit ) {
//    analogWrite(vis, 0);
//    analogWrite(ir, 0);
//    analogWrite(illum, 0);
//    digitalWrite(indicator, LOW);
    dblPressed = false;
    if (millis() - current_t >= sleepTimeout) {
      sleep_mode();
    }
  }
}

///////////////////////////////
///      Rotary Switch      ///
///////////////////////////////

int getRotaryPos() {
  float switchValFlt = round(analogRead(rotarySwitch) / threshold);
  int val = switchValFlt;
  return val;
}

void setOutputs() {
  int pos = getRotaryPos();
  analogWrite(vis, visVal[pos]);
  analogWrite(ir, irVal[pos]);
  illumBrightness = illumVal[pos];
  if (pos == programPos) {
    analogWrite(illum, illumBrightness);
    program();
    return;
  }

  if (pulsePerSec == 0) {
    analogWrite(illum, illumBrightness);
  } else { // Set up illum flashing
    if (illumBrightness != 0) {
      doIllumLoop = true;
    }
  }
}

///////////////////////////////
///       Programming       ///
///////////////////////////////

void program() {
  programming = true;
  blinkIndicator(1, true);
  // Wait 5 sec, cancel otherwise
  interrupts();
  time_t t = millis();
  while (programming) {
    if (millis() - t >= 5000) {
      analogWrite(vis, 0);
      analogWrite(ir, 0);
      analogWrite(illum, 0);
      digitalWrite(indicator, LOW);
      pulsePerSec = 0;
      break;
    }
  }
  programming = false;
}

void getPulsePerSec() {
  pulsePerSec = ppsVal[getRotaryPos()];
  if (pulsePerSec != 0) {
    flashRate = flashRateBase / (2 * pulsePerSec);
    blinkIndicator(pulsePerSec, false);
  }
}

void blinkIndicator(int blinkNum, bool endHigh) {
  int count = 0;
  bool blinkState = digitalRead(indicator), buttonPressed_ = buttonPressed;
  interrupts();
  time_t currentMillis, previousMillis = millis();
  int stateChanges = (2*blinkNum) - endHigh + blinkState;
  while (count < stateChanges && buttonPressed_ == buttonPressed) {
    currentMillis = millis();
    if (currentMillis - previousMillis >= blinkSpeed) {
      previousMillis = currentMillis;
      blinkState = !blinkState;
      digitalWrite(indicator, blinkState);
      count++;
    }
  }
}

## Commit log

2022-12-01 added circuit layout and diagram
2023-02-17 Added thread tests | added blockier body with double battery compartment
    [Battery Cover.stl, Laser Base.stl, Laser Body.stl]
2023-02-17 many changes
    Changelog:
    - Rotary Switch hole is too far forward, moved it towards the back 2mm
    - missing trench for body/lid near battery compartment
    - battery Positive wire hole wasn't elongated when battery compartment was
    - Nut trench for the Rotary Switch isn't deep enough
    - Made lid side of lid/body interface smaller so that it seats better
    [Battery Cover.stl, GAL Rail Mount.stl, Selector Cap.stl]
2023-02-17 fixed battery compartment
2023-02-20 Improved selector cap fitment
    [Selector Cap.stl]
2023-02-20 Increased rail mount nut hold thickness
    [GAL Rail Mount.stl]
2023-02-20 changed lid_body interface to be more print friendly
2023-02-20 actually increased the rotary switch hole, increased vertical laser windage nut hole
2023-02-21 decreased rotary switch hole, decreased vert_windage_nut hole height
2023-02-21 moved laser front hole down to line up with spring holes
2023-02-21 moved laser hole back up, moved laser back spring up
2023-02-21 added rotary switch detent on bottom of lid, improved vert_windage nut hole
2023-02-22 cleanup, added v2 flicker video
    [BOM.csv, Battery Cover.stl, GAL.step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]
2023-02-23 Added Falstad Circuit
2023-02-23 updated link to falstad circuit
2023-02-28 Create Wiring Diagram.png
2023-03-08 File reorganization
    [BOM.csv, Battery Cover.stl, GAL Rail Mount.stl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]
2023-03-08 updated stl to be in print orientation
    [Battery Cover.stl, GAL Rail Mount.stl, Selector Cap.stl]
2023-03-20 Renders and upgraded laser parts
    [Laser Base.stl, Laser Body.stl]
2023-09-13 reorg for v2
    [BOM.csv, Battery Cover.stl, GAL Rail Mount.stl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]
2023-09-17 Create PCB Wire Diagram.png
2023-10-02 push for merge
    [BOM.csv, Battery Cover.stl, Body_Variants.step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]
2023-11-07 Update GAL_Build_Guide.pdf
    Added ‘Prepping the Wires’ section | Added ‘Programming the ATtiny84’ Step 5 name
2023-12-13 Updated missing features and shortened 18650 battery compartment
2023-12-14 adding STEP and STL edits by zb
    [GAL_TPUgaskets-retention_zb_edit.step, GAL_TPUgaskets-retention_zb_edit.stl, GAL_batterycap-retention_zb_edit.step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]
2023-12-15 zb edit updates
    [GAL_TPU_gaskets_retention_zb.step, GAL_TPU_gaskets_retention_zb.stl, GAL_TPUgaskets-retention_zb_edit.step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]
2023-12-23 re-exported STLs as smaller files
    [battery_cap.stl, body_18650_jack.stl, laser_housing.stl]
2024-07-03 moving v2 to __Archive
    [BOM_PCB_GAL_v2_2023-10-05.csv, Body_Variants.step, GAL_TPU_gaskets_retention_zb.step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]
2024-07-03 initial v3 file release
    [FIRE_button_TPU.stl, GAL_body.stl, GAL_lid.stl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]
2024-07-04 added crane_port_spacer
    [crane_port_spacer.stl]
2024-07-11 adding PCB files
    [bom.csv, designators.csv, positions.csv]
2024-08-01 added zb's selector_knob mod
    [selector_knob_zb.step, selector_knob_zb.stl]
2024-08-01 renaming STLs to match numbering in build guide
    [01_GAL_body.stl, 02_laser_base.stl, 03_laser_housing.stl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]
2024-10-04 added new selector and lid, new reordered lid
    [11_selector_knob.stl, 11_selector_knob_2.stl, GAL Lid_v3_1_reordered.stl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]
2024-10-22 added sf pattern GAL body and guide
    [SureFire_Pattern_Illumintor_GAL_Body.stl]
2025-01-02 reordered community_mods folder
    [mod_01_selector_knob_zb.stl, mod_02_SureFire_Pattern_Illumintor_GAL_Body.stl, mod_03_GAL_Lid.stl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]
2025-01-24 CODE update to reduce power usage when idle
